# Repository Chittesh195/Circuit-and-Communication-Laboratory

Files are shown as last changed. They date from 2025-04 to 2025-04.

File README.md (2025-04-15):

# 📐 Triangular Wave Generator Using Op-Amp (LM741)

### 🔧 23ECE286 – Circuits and Communication Lab Term Project  

---

## 📘 Project Overview

This project focuses on the **design, simulation, and hardware implementation** of a **triangular wave generator** using **operational amplifiers (LM741)**. The waveform's frequency is **adjustable between 250 Hz and 2.5 kHz**, making it suitable for various signal processing and waveform synthesis applications.

---

## 🎯 Objectives

- Design a **Schmitt Trigger** using LM741 to generate a square wave.
- Build an **Integrator** circuit to convert the square wave into a triangular waveform.
- Achieve a **variable frequency range of 250 Hz to 2.5 kHz**.
- Simulate the circuit using **LTSpice**.
- Implement and test the circuit using **hardware and oscilloscope measurements**.
- Analyze waveform quality and component impact.

---

## 🛠️ Circuit Description

The circuit consists of two main stages:

1. **Schmitt Trigger (Comparator)**
   - Uses LM741 with positive feedback to generate a square wave.
   - Switching thresholds set via voltage divider network.

2. **Integrator**
   - Converts the square wave into a triangular wave.
   - Built with LM741, resistors, and capacitors.

---

## ⚙️ Key Components

| Component | Specification |
|---|---|
| Op-Amp | LM741 × 2 |
| Potentiometer | 4.7 kΩ to 470 kΩ (variable resistor) |
| Resistors | 1 kΩ, 4.7 kΩ, 12 kΩ |
| Capacitor | 0.1 µF |
| Power Supply | ±12 V |
| Oscilloscope | For waveform observation  |
| Breadboard & Wires  | For hardware setup |

---

## 🔢 Frequency Calculations

Formula used:
```
f = R1 / (4 × R × C × R2)
```

- For **250 Hz**: R = 47 kΩ  
- For **2.5 kHz**: R = 4.7 kΩ  

---

## 🧪 Simulation & Implementation

- **LTSpice** used for waveform validation.
- Hardware circuit implemented on **breadboard**.
- **Oscilloscope** verified clean triangular wave output.
- Adjusting the potentiometer varied the frequency across the desired range.

---

## 📈 Results

- **Waveform Quality**: Stable triangular waveform across entire frequency range.
- **Frequency Range Achieved**: 250 Hz to 2.5 kHz.
- **Simulation and experimental results** closely matched.

| Potentiometer (R) | Frequency (Approx.) |
|---|---|
| 47 kΩ | 250 Hz |
| 4.7 kΩ | 2.5 kHz |

---

## ⚠️ Challenges & Solutions

| Challenge | Solution |
|---|---|
| Resistor value mismatches | Used nearest standard values and recalculated |
| Frequency drift | Used precision 1% tolerance components  |
| Op-amp limitations | Optimized for LM741’s bandwidth |

---

## 📌 Applications

- Signal and function generators  
- Audio waveform synthesis  
- Communication systems (modulation/wave shaping)  

---

## 📚 References

1. Sedra A., Smith K. C., *Microelectronic Circuits*, 6th ed., Oxford University Press, 2010.  
2. Texas Instruments, *Designing With Operational Amplifiers*, [TI Report](https://www.ti.com/lit/pdf/tidu020)

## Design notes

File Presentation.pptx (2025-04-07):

## 23ECE286 Circuits and Communication Laboratory

Term Project

Date: 04-04-2025

Group ID: 5

Group Members:
- ASWIN K(CB.EN.U4ECE23207)
- CHITTESH .S(CB.EN.U4ECE23212)
- MAMIDI RAHUL(CB.EN.U4ECE23227)

## Overview

- Introduction
- Design
- Working Principle
- Calculation
- Simulation
- Results

## Project Topic:

1. Design and implement a circuit using op-amp to generate a triangular wave with variable frequency 250 Hz to 2.5 kHz..

## Introduction:

- A triangular wave generator is a fundamental circuit used in signal processing, waveform synthesis, and function generators. The circuit typically consists of an integrator and a Schmitt trigger.
- This involves configuring an operational amplifier (LM741). The Schmitt trigger provides a square wave, which the integrator converts into a triangular waveform. This document presents a triangular wave generator using op-amps with a variable frequency range of 250 Hz to 2.5 kHz.

## Design:

1. Schmitt Trigger (Comparator): An op-amp-based comparator generates a square wave by switching between two threshold voltage levels.
2. Integrator: A second op-amp is used as an integrator with a capacitor and resistor in its feedback loop to convert the square wave into a triangular waveform.
Components requirements:
- Two LM741 Op-Amps
- Resistors: 12kΩ, 4.7kΩ, 1kΩ
- Capacitor: 0.1μF
- DC Power Supply: +12V, -12V

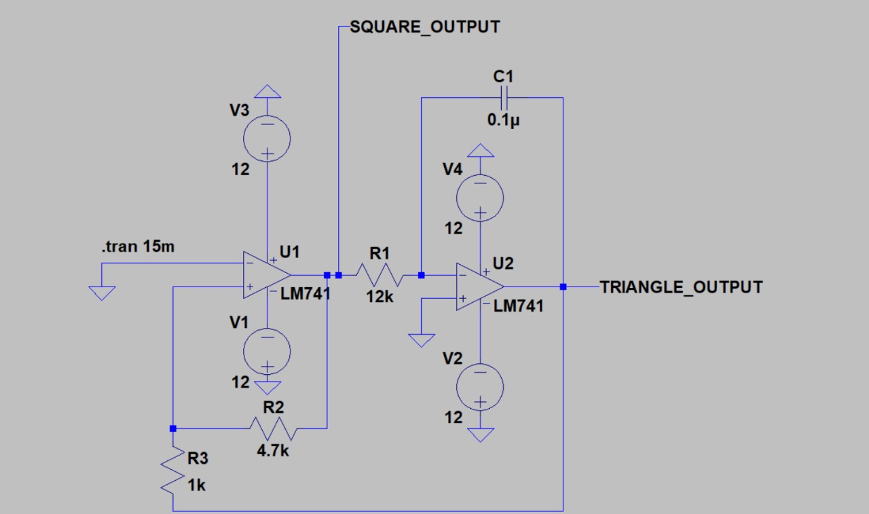
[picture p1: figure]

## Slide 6

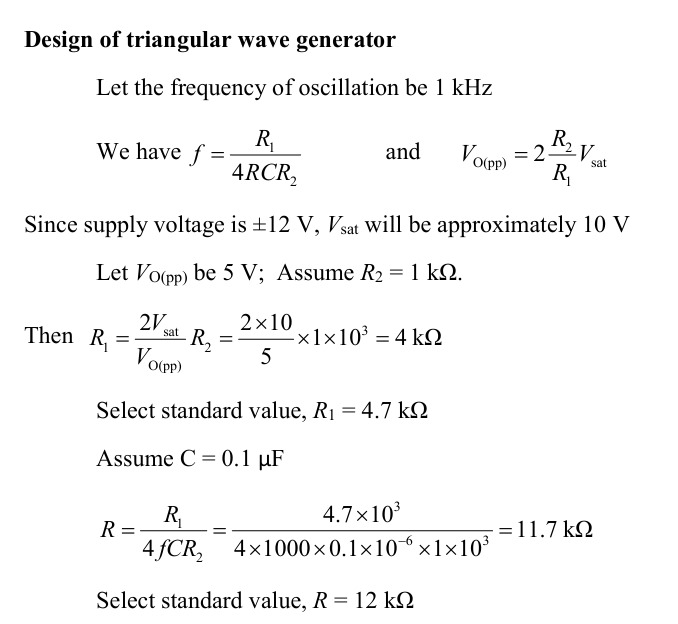
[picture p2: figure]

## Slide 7

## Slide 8

Simulation For Frequency 250 Hz:

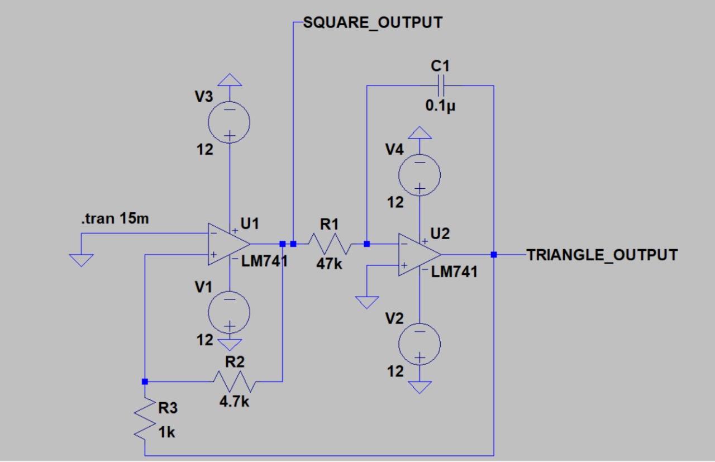
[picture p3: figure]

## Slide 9

OUTPUT FOR 250 Hz:

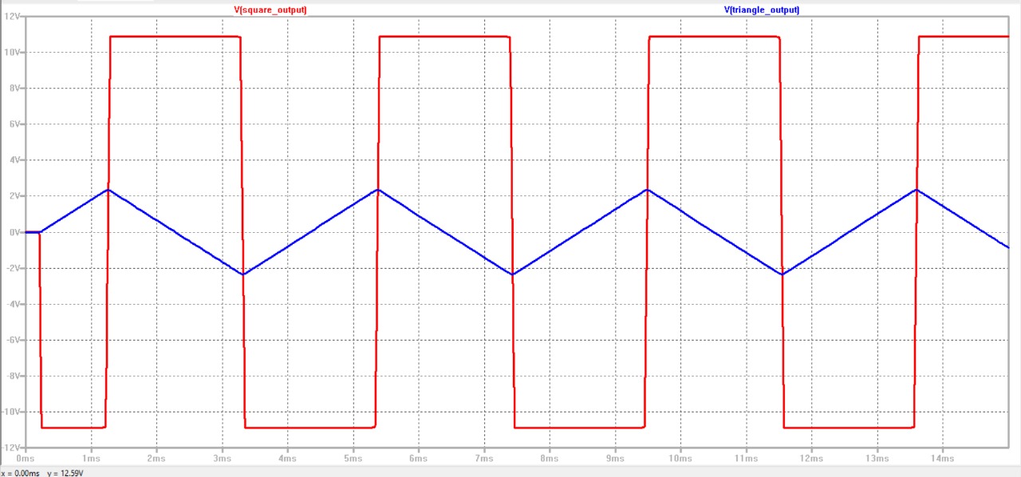
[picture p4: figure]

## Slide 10

Simulation For 2.5KHz:

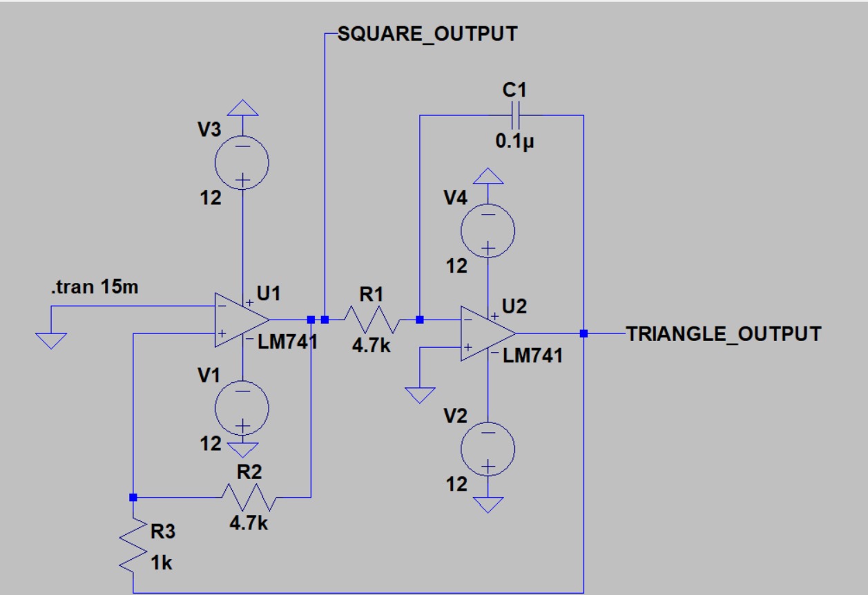
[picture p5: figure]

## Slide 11

Output for 2.5KHz:

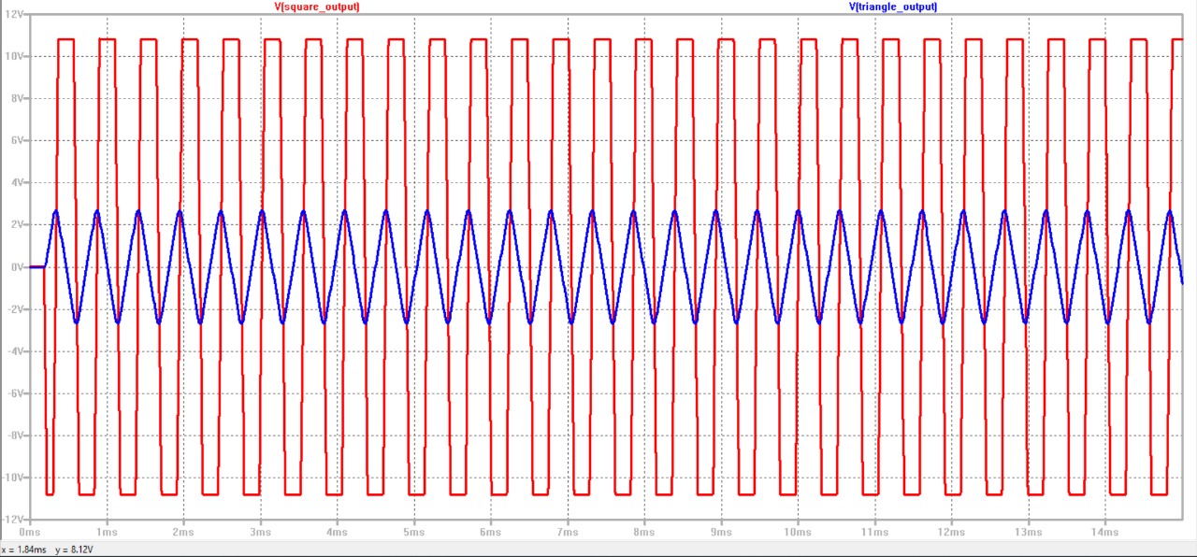
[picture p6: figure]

## WORKING PRINCIPLE

- Working Principle:
1. Square Wave Generation: The first op-amp (U1) is used as a Schmitt trigger. The inverting terminal is connected to a feedback network, while the non-inverting terminal is set at a reference voltage. When the output crosses a certain threshold, the op-amp switches states, producing a square wave.
2. Triangular Wave Generation: The square wave is then fed into an integrator (U2), which consists of an op-amp, a capacitor, and a resistor. The integrator converts the input square wave into a triangular waveform as it continuously integrates the square wave signal.
3. Frequency Control: The frequency can be adjusted by varying the values of resistors or the capacitor in the integrator stage.

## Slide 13

1. Square Wave Output (SQUARE_OUTPUT):
  1. The Schmitt trigger (U1) produces a square wave.
  2. The frequency of the square wave depends on the resistor and capacitor values in the feedback loop.
  3. The amplitude is approximately equal to the op-amp’s supply voltage (+12V and -12V).
2. Triangular Wave Output (TRIANGLE_OUTPUT):
  1. The integrator (U2) converts the square wave into a triangular wave.
  2. The slope of the triangular wave depends on the RC time constant of the integrator.
  3. The frequency is determined by the Schmitt trigger’s output.
- Captured Waveforms from Simulation
- Square Wave (SQUARE_OUTPUT): Alternates between +12V and -12V.
- Triangular Wave (TRIANGLE_OUTPUT): A continuous linear ramp up and down.

## :OUTPI

OUTPUT

Output Signal:

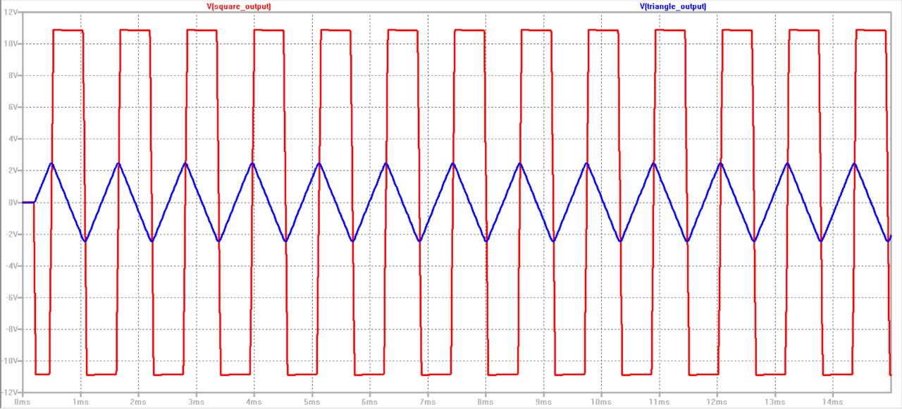
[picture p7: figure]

## Circuit

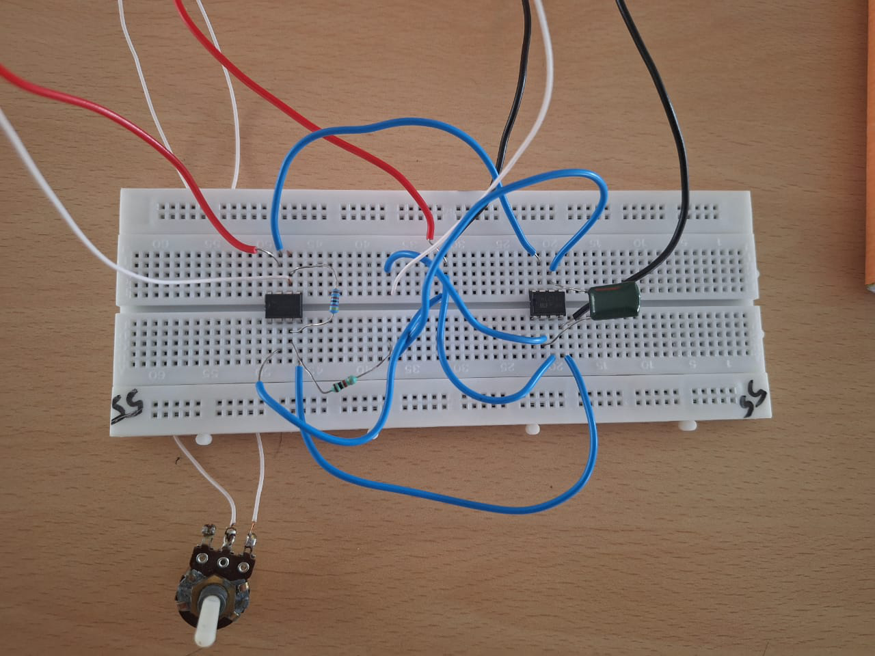
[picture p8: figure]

## Implemented Results

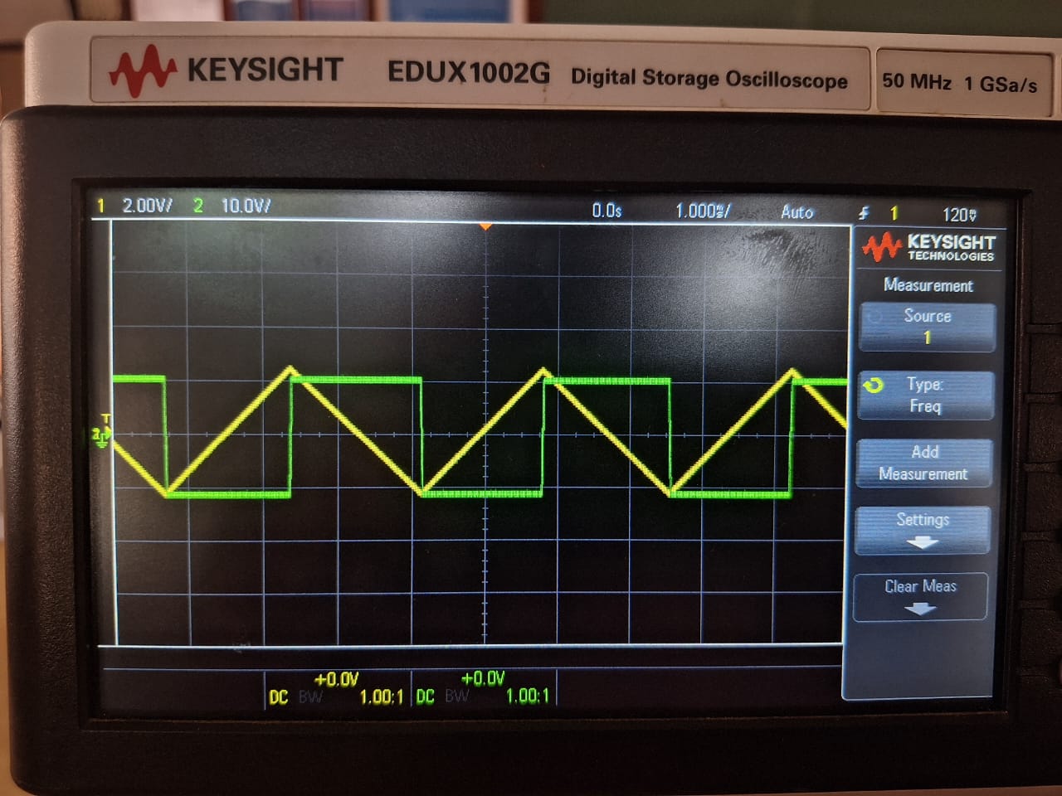
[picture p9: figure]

Potentiometer at 47 KΩ for 250Hz (Implemented)

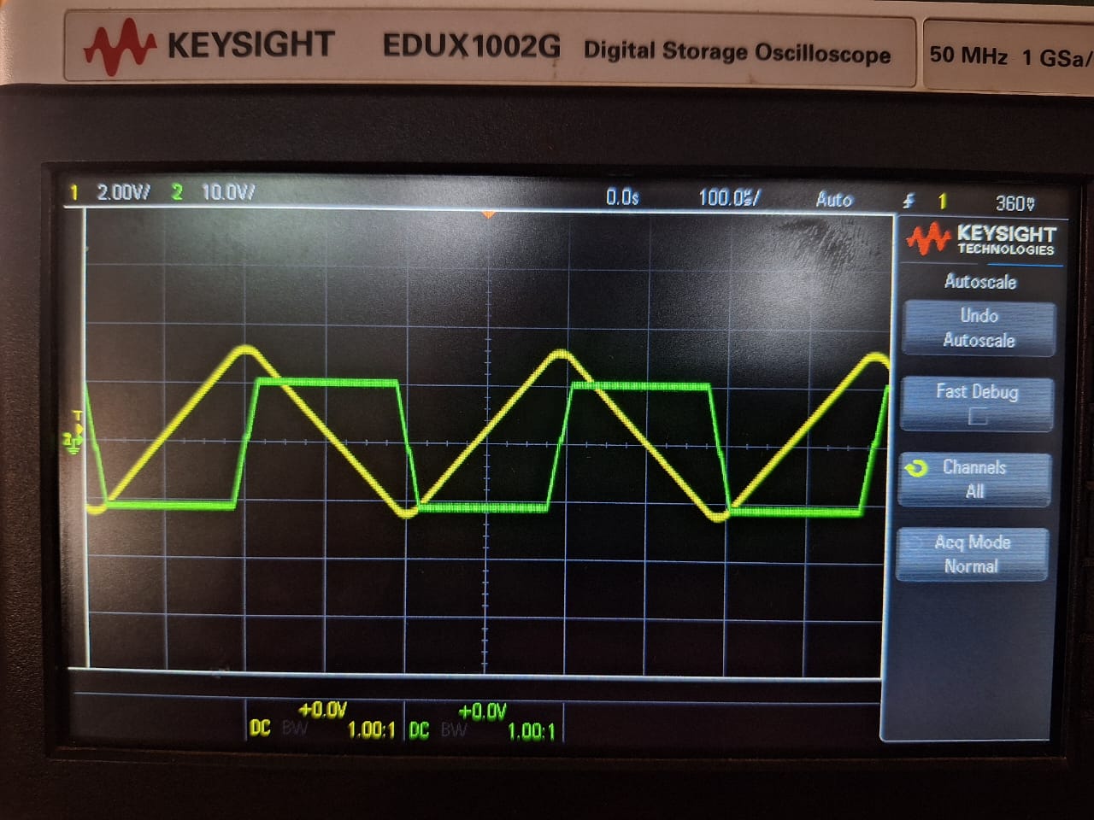
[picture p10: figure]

Potentiometer at 4.7 KΩ for 2.5KHz (Implemented)

## PCB layout

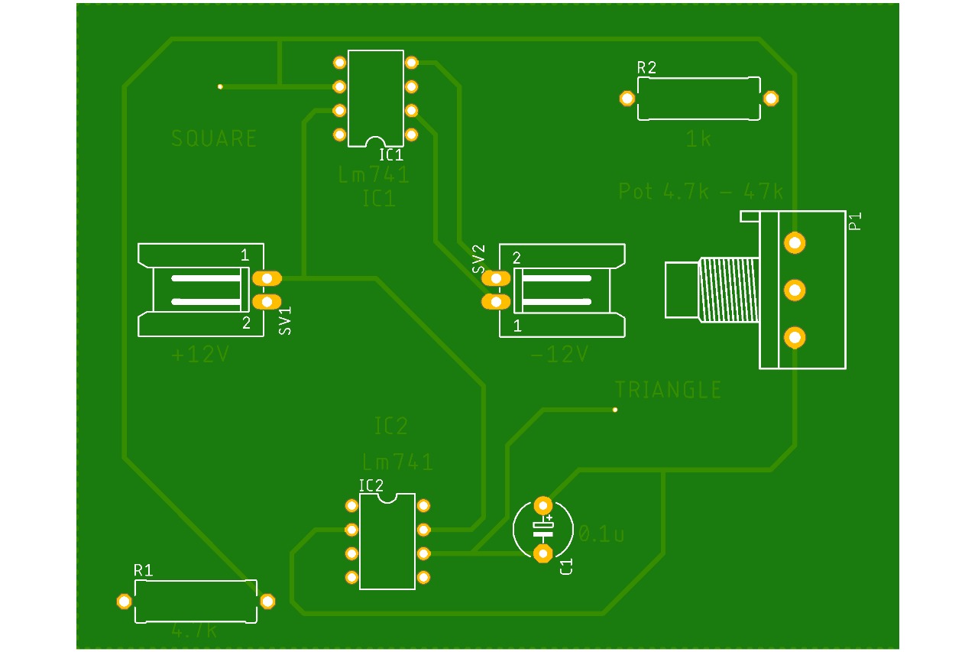
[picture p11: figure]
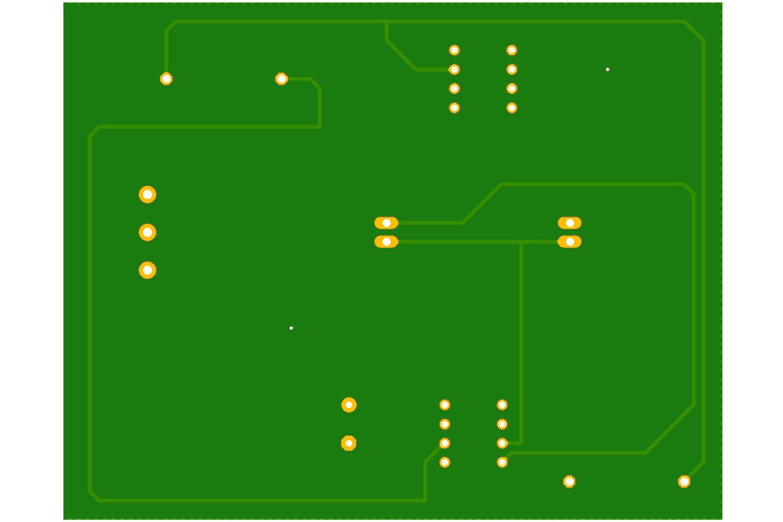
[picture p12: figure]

Front

Back

## Challenges and Solutions

Challenges Encountered:
Ensuring a stable triangular waveform across 250 Hz to 2.5 kHz was difficult due to component
tolerances and design constraints.
1. Frequency Stability Issues – Resistor and capacitor tolerances caused variations in oscillation
frequency, affecting waveform accuracy.
2. Resistor Value Mismatch – Standard resistor values didn’t match calculated values, slightly
altering the Schmitt Trigger’s threshold.
3. Component Limitations – The LM741 op-amp had bandwidth constraints, causing minor
distortions at higher frequencies.

## Challenges and Solutions

Solutions Implemented:
To improve accuracy, we optimized component selection.
1. Precision Components – Used 1% tolerance resistors and adjusted capacitors for stable
performance.
2. Threshold Adjustments – Recalculated Schmitt Trigger thresholds using available resistor
values.
3. Testing & Optimization – Iterative testing with an oscilloscope helped refine resistor values
and improve stability.

## RESULTS:

Results:
1. The circuit successfully generates a triangular wave from a square wave input.
2. The frequency of the triangular wave is adjustable within the desired range.
3. The simulation results confirm the theoretical calculations.
4. The output waveforms match expected characteristics.
Conclusion :This project demonstrates the design and implementation of a triangular wave generator using op-amps. The use of a Schmitt trigger and an integrator enables the generation of stable and adjustable waveforms. The circuit finds applications in function generators, signal processing, and waveform synthesis.

## Thank you

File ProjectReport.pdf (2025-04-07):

### 23ECE286 CIRCUITS AND COMMUNICATION LAB

### Design and implement a circuit using op-amp to generate a triangular

wave with variable frequency 250 Hz to 2.5 kHz.

TERM PROJECT REPORT

Submitted by

CB.EN.U4ECE23207 | Ashwin K
CB.EN.U4ECE23212 | Chittesh S
CB.EN.U4ECE23227 | M Rahul

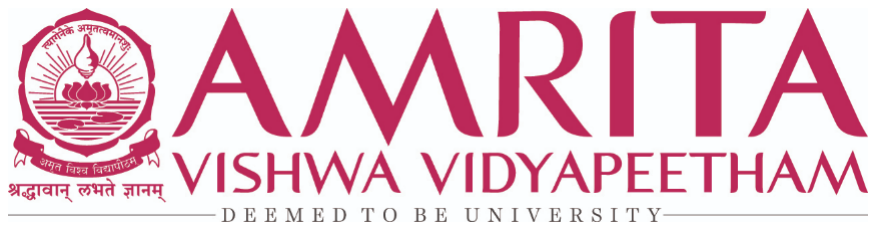
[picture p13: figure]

AMRITA SCHOOL OF ENGINEERING

AMRITA VISHWA VIDYAPEETHAM

COIMBATORE 641112

April 2025

Date of Submission

(04/04/2025)

Students signature

Faculty | Lab Staff

## Table of Contents

Topic | Page No.
Introduction | 3
Objectives | 3
Methodology | 3
Circuit Design and Components | 4
Implementation | 7
Results | 8
Discussion | 10
Challenges and Solutions | 11
Conclusion | 12
References | 12

Introduction

Design and implement a triangular wave generator using an op-amp (LM741) with a variable frequency

range of 250 Hz to 2.5 kHz. The circuit consists of a Schmitt Trigger (comparator stage) to generate a

square wave and an integrator (waveform conversion stage) to produce a triangular waveform. The

design should ensure a stable and distortion-free output with smooth frequency control. The circuit is

analysed through simulation to verify waveform accuracy. The project finds applications in signal

processing, audio synthesis, and function generation.

Objectives

- Design a Schmitt Trigger using an LM741 op-amp to generate a square wave.
- Design an Integrator Circuit to convert the square wave into a triangular waveform.
- Select Appropriate Components (resistors and capacitors) to achieve a frequency range of 250 Hz

to 2.5 kHz.

- Simulate the Circuit using LTSpice to verify waveform accuracy.
- Analyse Output Waveforms to ensure they match theoretical expectations.
- Evaluate Component Variations and their effect on frequency and amplitude.
- Implement the Circuit on Hardware using a breadboard or PCB.
- Provide a ±12V Power Supply for proper op-amp operation.
- Test the Circuit Using an Oscilloscope to observe waveform characteristics.
- Compare Simulation and Experimental Results to validate design accuracy.

Methodology

We began by researching different triangular wave generation methods and selected a Schmitt Trigger and

integrator circuit for stable waveform generation. In the design phase, we chose LM741 op-amps and

calculated resistor and capacitor values to achieve a frequency range of 250 Hz to 2.5 kHz. The Schmitt

Trigger used a voltage divider to set threshold voltages for square wave generation, while the integrator

converted it into a triangular waveform.

- Simulated the circuit in LT Spice to verify waveform accuracy.
- Tested different resistor and capacitor values to analyze frequency variation.
- Confirmed the Schmitt Trigger's square wave and the integrator’s triangular output.

After successful simulation, we assembled the circuit on a breadboard and powered it with a ±12V supply.

An oscilloscope was used to measure the output waveforms, confirming stable and adjustable triangular

waves. The circuit’s performance was evaluated by measuring frequency stability across different settings.

Adjustments were made to optimize the design for smooth frequency control.

Circuit Design and Components

The circuit has two main stages:

### 1. Schmitt Trigger (Comparator Stage)

- An LM741 op-amp is used as a comparator to create the Schmitt Trigger.
- It switches between two preset voltage levels, generating a square wave.
- The output alternates between +12V and -12V as the input crosses the threshold values.

### 2. Integrator (Waveform Conversion Stage)

- The square wave from the Schmitt Trigger is fed into an integrator circuit.
- The integrator is built using an LM741 op-amp, a resistor, and a capacitor.
- It gradually converts the square wave into a smooth triangular waveform.
S.No | Name of The Component | Required Quantity
1. | DC Power Supply (0-200V) | 1
2. | Op-Amp (LM741) | 2
3. | Resistors (1kΩ, 4.7kΩ) | 1 each
4. | Function Generator | 1
5. | Digital Storage Oscilloscope | 1
6. | Breadboard | 1
7. | Connecting Wires | As Required
8. | Probes | As Required
9. | Potentiometer (4.7 KΩ- 470K Ω) | 1
Component | Function
DC Power Supply (0-200V) | Provides ±15V to power the op-amp and ensures stable operation.
Op-Amp (LM741) | Used in two stages: Schmitt Trigger (generates square wave) and Integrator (converts square wave to triangular wave).
Resistors (1kΩ, 4.7kΩ) | Define Schmitt Trigger threshold voltages, control feedback for stable oscillation, and set the integration time constant in triangular wave generation.
Function Generator | Generates a 10V, 100 Hz sinusoidal input to test the Schmitt Trigger’s response to noise.
Digital Storage Oscilloscope (DSO) | Monitors output waveforms, measures switching thresholds, and verifies circuit performance.
Breadboard | Provides a platform for assembling and modifying the circuit easily.
Connecting Wires | Establishes connections between components .
Probes | Connects the oscilloscope for accurate signal measurement and analysis.

Design of Triangular Wave Generator

Let the frequency of oscillation be 1 kHz

We have:

f =

R1
4RCR2

and

VO(pp) = 2

R2
R1

Vsat

Since the supply voltage is ±12V, VsatVsat will be approximately 10V

Let VO(pp) be 5V; Assume R2 = 1kΩ.

Then,

R1 =

2Vsat

VO(pp)

R2 =

2 × 10
5

× 1 × 10³ = 4kΩ

Select the standard value, R1 = 4.7kΩ

Assume C = 0.1 µF

R =

R1
4fCR2

=

4.7 × 10³
4 × 1000 × 0.1 × 10⁻⁶ × 1 × 10³ = 11.7kΩ

Select the standard value, R = 12kΩ

To calculate the resistor RR for frequencies of 250 Hz and 2.5 kHz, we use the given formula:

R =

R1
4fCR2

Given values:
- R1 = 4.7kΩ = 4700Ω
- C = 0.1μF = 0.1 × 10⁻⁶F
- R2 = 1kΩ = 1000Ω

For f = 250Hz:

R =

4700
4 × 250 × 0.1 × 10⁻⁶ × 1000 =

4700
0.1

= 47kΩ

For f = 2. 5kHz (2500 Hz):

R =

4700
4 × 2500 × 0.1 × 10⁻⁶ × 1000 =

4700
1
R = 4.7kΩ

So the resistor values are:

- For 250 Hz: R = 47kΩR=47kΩ
- For 2.5 kHz: R = 4.7kΩR=4.7kΩ

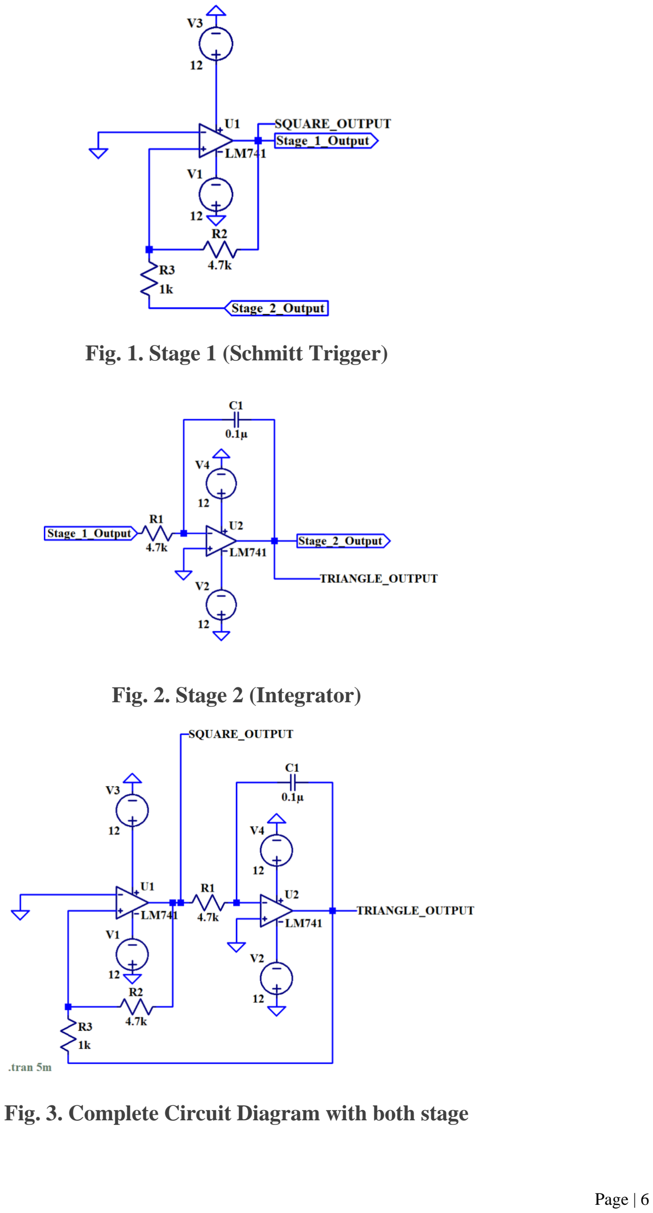
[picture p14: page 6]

Fig. 1. Stage 1 (Schmitt Trigger)

Fig. 2. Stage 2 (Integrator)

Fig. 3. Complete Circuit Diagram with both stage

Implementation

The circuit was first assembled on a breadboard, ensuring that all components were placed correctly for

easy modifications. A DC power supply was set up to provide a stable ±12V to power the LM741

operational amplifiers. Before building the full circuit, the Schmitt Trigger stage was constructed first to

generate a square wave signal.

- Schmitt Trigger Stage:
- A voltage divider network was used to set the upper and lower threshold voltages.
- The input signal was applied to the inverting terminal of the op-amp through a resistor.
- Positive feedback was introduced to create hysteresis, ensuring stable square wave

oscillation.

Once the Schmitt Trigger output was verified, the integrator circuit was added to convert the square wave

into a triangular waveform. A capacitor and resistor network was used to perform the integration process

smoothly. The circuit was then tested to confirm that the output waveform was stable and matched

expectations.

- Simulation and Testing:
- The design was first simulated using LTSpice before hardware testing.
- Simulated waveforms were analysed for stability, frequency accuracy, and response to

input variations.

- After confirming correct operation in the simulation, the circuit was built on hardware.

Finally, the assembled circuit was tested using a digital storage oscilloscope (DSO) to measure the output

waveforms. The oscilloscope verified that the circuit generated a stable and adjustable triangular wave.

The results were compared with the simulation, ensuring the design functioned correctly across the entire

frequency range.

Challenges During Implementation

- Resistor Value Mismatch: Exact resistor values were unavailable, requiring the use of the

closest standard values. This led to recalculations of threshold voltages and minor circuit

adjustments to maintain proper oscillation.

- Frequency Stability Issues: The triangular wave frequency fluctuated slightly due to component

tolerances, especially in resistors and capacitors. Using 1% tolerance components and fine-tuning

resistor values improved accuracy.

- Solution & Success: Through careful component selection, recalibration, and iterative testing,

we successfully stabilized the circuit. The final implementation produced a reliable and

adjustable triangular waveform within the desired 250 Hz to 2.5 kHz range, closely matching the

simulated results.

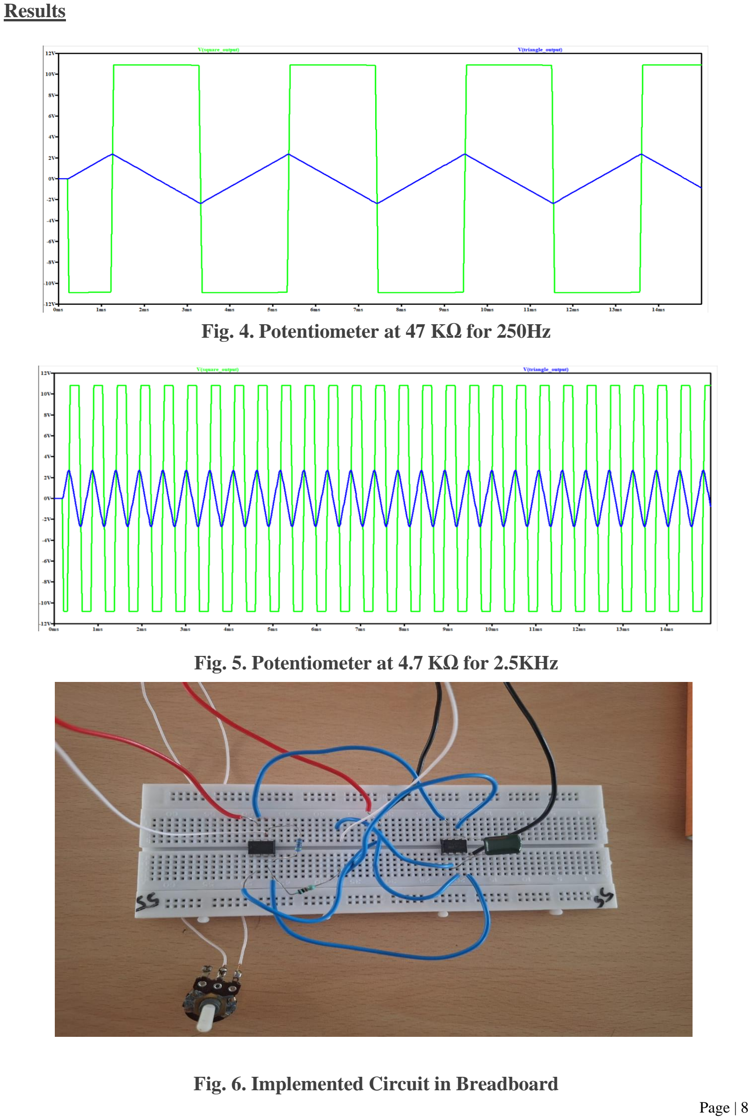
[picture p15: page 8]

Results

Fig. 4. Potentiometer at 47 KΩ for 250Hz

Fig. 5. Potentiometer at 4.7 KΩ for 2.5KHz

Fig. 6. Implemented Circuit in Breadboard

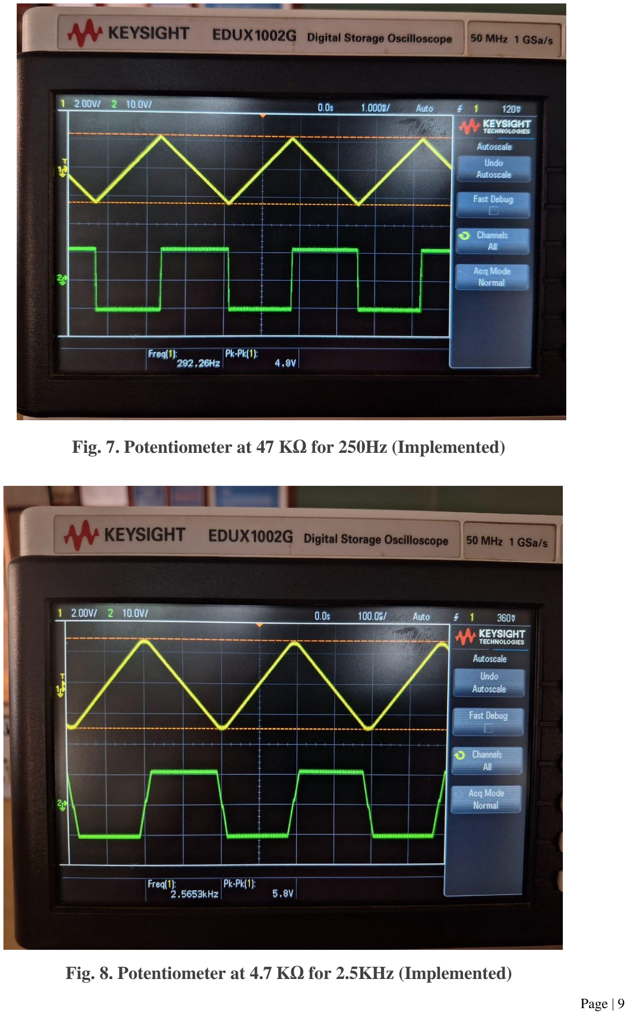
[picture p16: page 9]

Fig. 7. Potentiometer at 47 KΩ for 250Hz (Implemented)

Fig. 8. Potentiometer at 4.7 KΩ for 2.5KHz (Implemented)

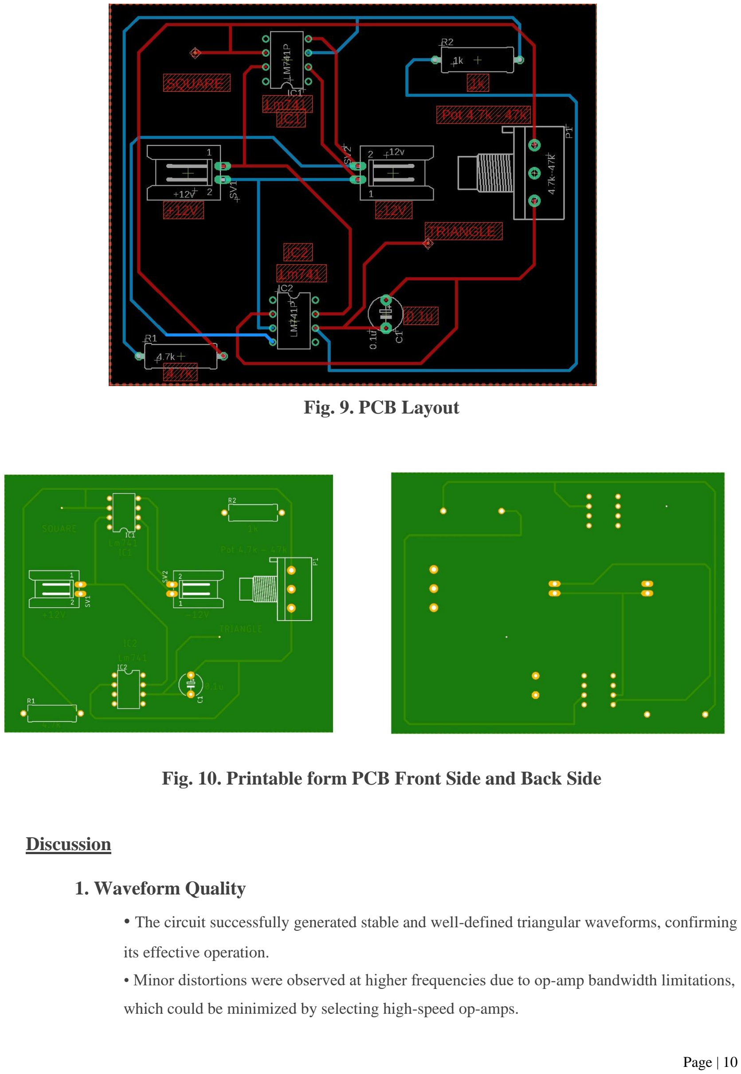
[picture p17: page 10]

Fig. 9. PCB Layout

Fig. 10. Printable form PCB Front Side and Back Side

Discussion

### 1. Waveform Quality

- The circuit successfully generated stable and well-defined triangular waveforms, confirming

its effective operation.

- Minor distortions were observed at higher frequencies due to op-amp bandwidth limitations,

which could be minimized by selecting high-speed op-amps.

### 2. Impact of Component Selection

- The resistor and capacitor values significantly influenced the waveform’s frequency,

amplitude, and stability.

- Increasing the capacitor value lowered the frequency, while decreasing it resulted in a

higher frequency, demonstrating the sensitivity of the circuit to passive component variations.

### 3. Applications of the Circuit

- Widely used in function generators for producing precise waveform signals.
- Essential in audio synthesis applications, such as musical tone generation and sound

modulation.

- Plays a crucial role in signal processing circuits, including modulation systems and

waveform shaping in communication systems.

Challenges and Solutions

Challenges Encountered:

Ensuring a stable triangular waveform across 250 Hz to 2.5 kHz was difficult due to component

tolerances and design constraints.

1. Frequency Stability Issues – Resistor and capacitor tolerances caused variations in oscillation

frequency, affecting waveform accuracy.

2. Resistor Value Mismatch – Standard resistor values didn’t match calculated values, slightly

altering the Schmitt Trigger’s threshold.

3. Component Limitations – The LM741 op-amp had bandwidth constraints, causing minor

distortions at higher frequencies.

Solutions Implemented:

To improve accuracy, we optimized component selection.

1. Precision Components – Used 1% tolerance resistors and adjusted capacitors for stable

performance.

2. Threshold Adjustments – Recalculated Schmitt Trigger thresholds using available resistor

values.

3. Testing & Optimization – Iterative testing with an oscilloscope helped refine resistor values

and improve stability.

Conclusion

1. The circuit successfully generates a triangular wave from a square wave input.
2. The frequency of the triangular wave is adjustable within the desired range.
3. The simulation results confirm the theoretical calculations.
4. The output waveforms match expected characteristics.

This project demonstrates the design and implementation of a triangular wave generator using op-amps.

The use of a Schmitt trigger and an integrator enables the generation of stable and adjustable waveforms.

The circuit finds applications in function generators, signal processing, and waveform synthesis.

References

[1] Sedra A and Smith K C, Microelectronic circuits, 6th ed. New York: Oxford University Press,

2010.

[2] Texas Instruments, "Designing With Operational Amplifiers: Basics and Best Practices," Texas

Instruments Application Report, Apr. 2013. [Online]. Available: https://www.ti.com/lit/pdf/tidu020

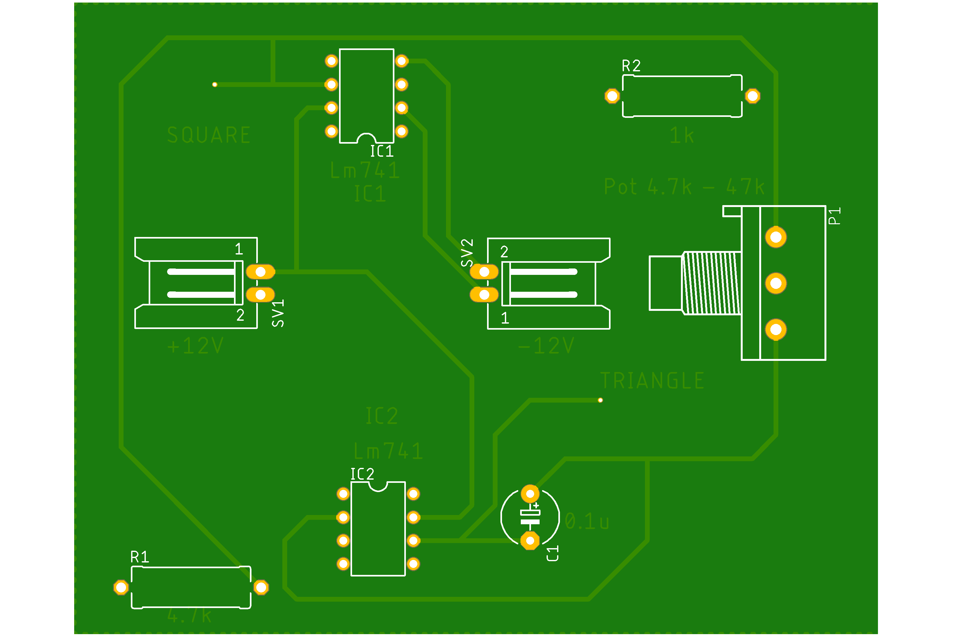
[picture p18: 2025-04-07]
PCB_JPG/final_Top.png

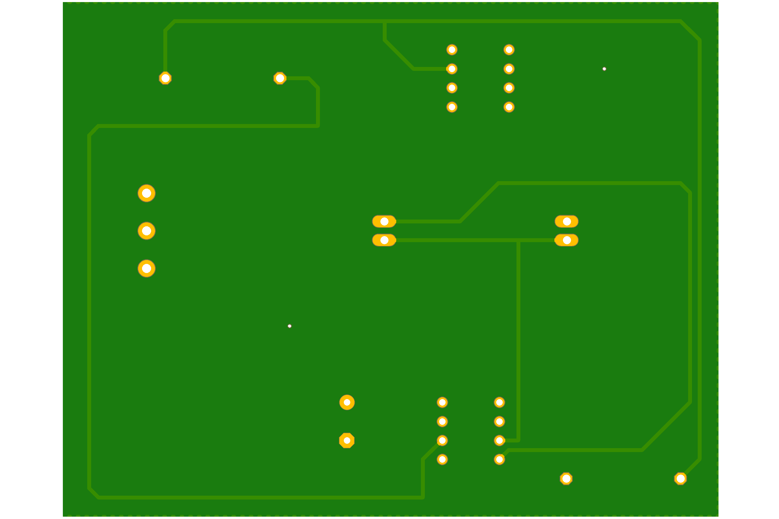
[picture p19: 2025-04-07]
PCB_JPG/final_Bottom.png

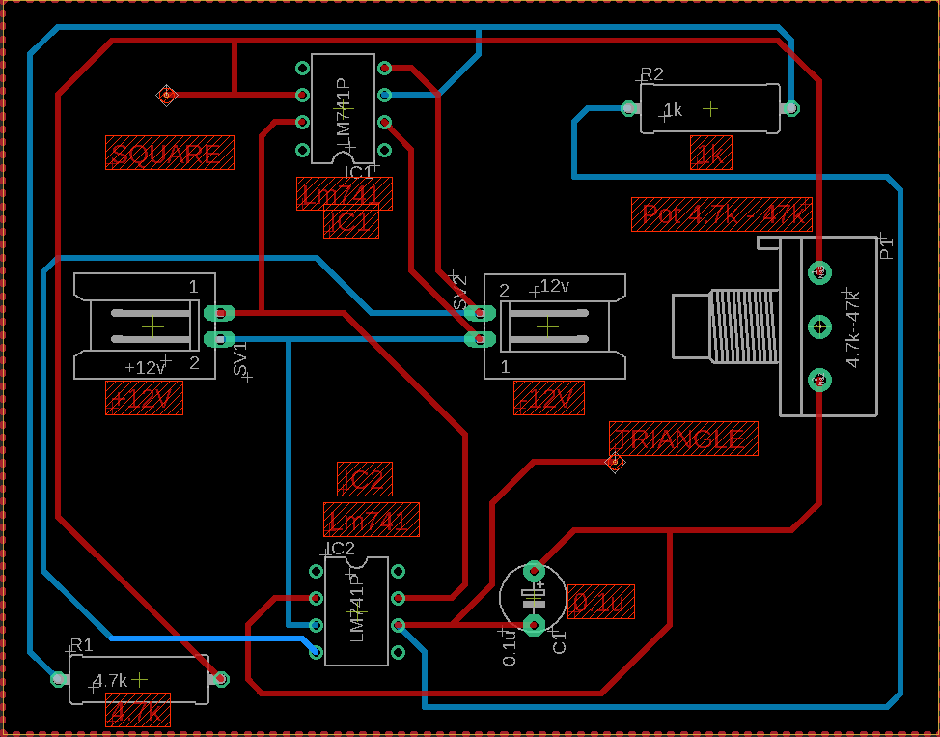
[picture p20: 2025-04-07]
PCB_JPG/final_raw.png

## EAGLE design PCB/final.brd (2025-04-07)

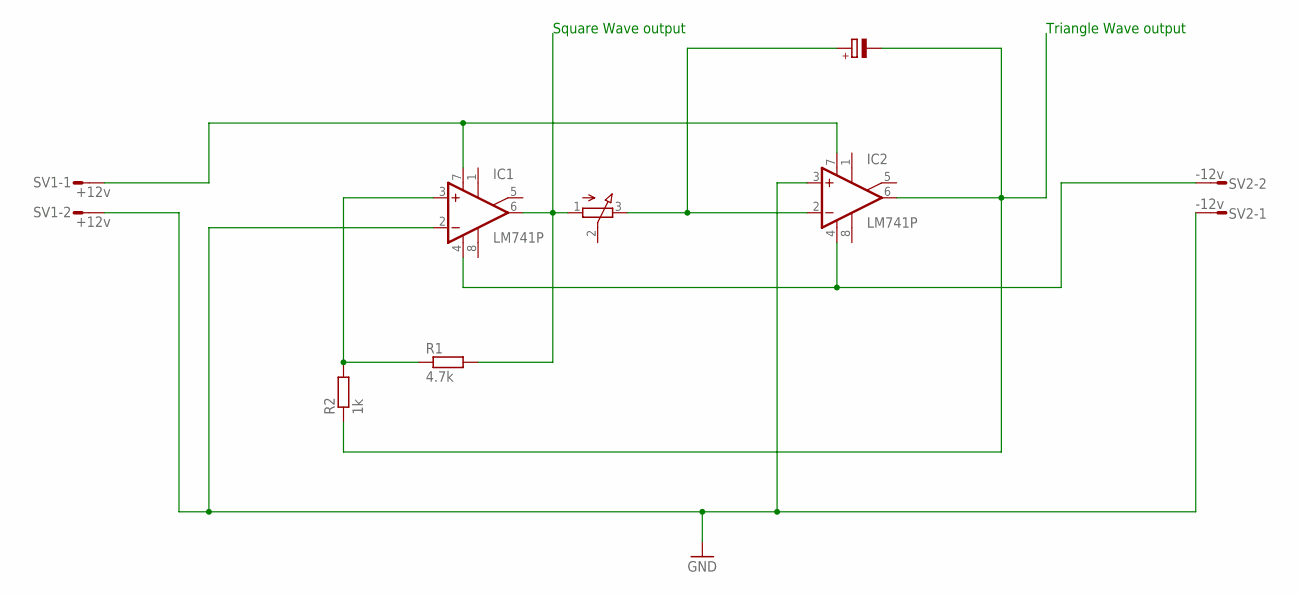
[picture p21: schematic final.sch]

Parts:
C1: 0.1u; E5-6
IC1, IC2: LM741P; DIL08
P1: 4.7k--47k; 3RP/1610N
R1: 4.7k; P0613/15
R2: 1k; P0613/15
SV1: +12v; L02P
SV2: -12v; L02P

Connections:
GND: IC1.2 (-IN), IC2.3 (+IN), SV1.2, SV2.1
unnamed: IC1.7 (V+), IC2.7 (V+), SV1.1
unnamed: C1.+, IC2.2 (-IN), P1.3 (E)
unnamed: C1.-, IC2.6 (OUT), R2.1
unnamed: IC1.3 (+IN), R1.1, R2.2
unnamed: IC1.6 (OUT), P1.1 (A), R1.2
unnamed: IC1.4 (V-), IC2.4 (V-), SV2.2

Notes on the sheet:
Square Wave output
Triangle Wave output

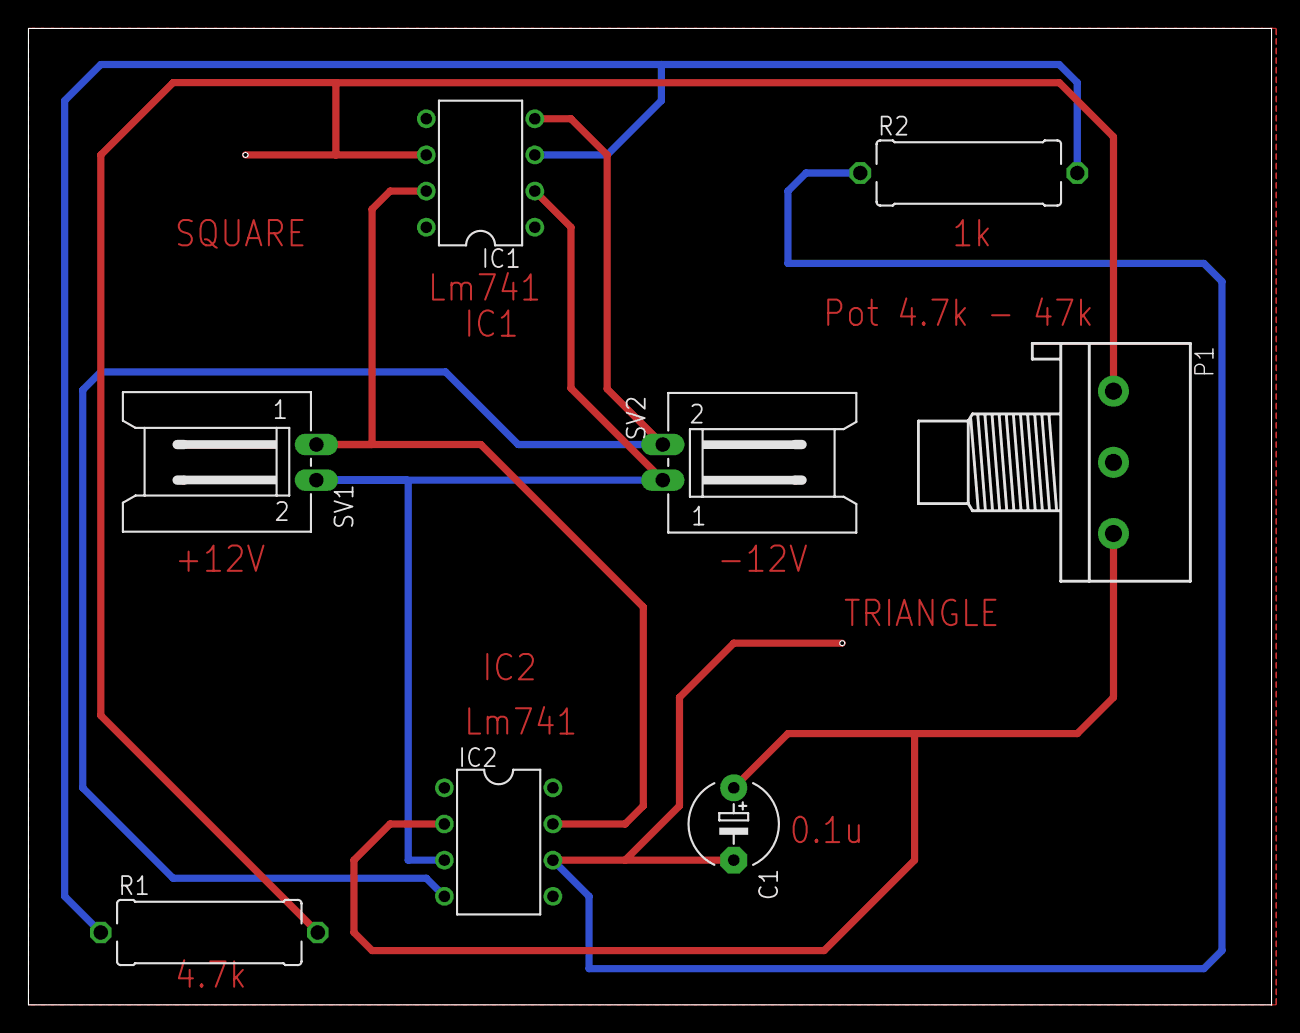
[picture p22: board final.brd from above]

Board: 2 copper layers, 87.3 x 68.6 mm, 8 parts (0 on the bottom side), 7 nets.
